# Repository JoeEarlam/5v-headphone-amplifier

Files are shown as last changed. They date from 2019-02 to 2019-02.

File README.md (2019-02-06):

# 5v-headphone-amplifier

A small, op-amp based headphone amplifier with a BOM cost of under £10 - think CMOY on steroids. Designed to run from 5V power, specifically cheap single-cell USB powerbanks, where it can be stuck to the side with velcro or double sided tape.

Uses an RC4580D, but any standard footprint SOIC-8 op-amp can be substituted.

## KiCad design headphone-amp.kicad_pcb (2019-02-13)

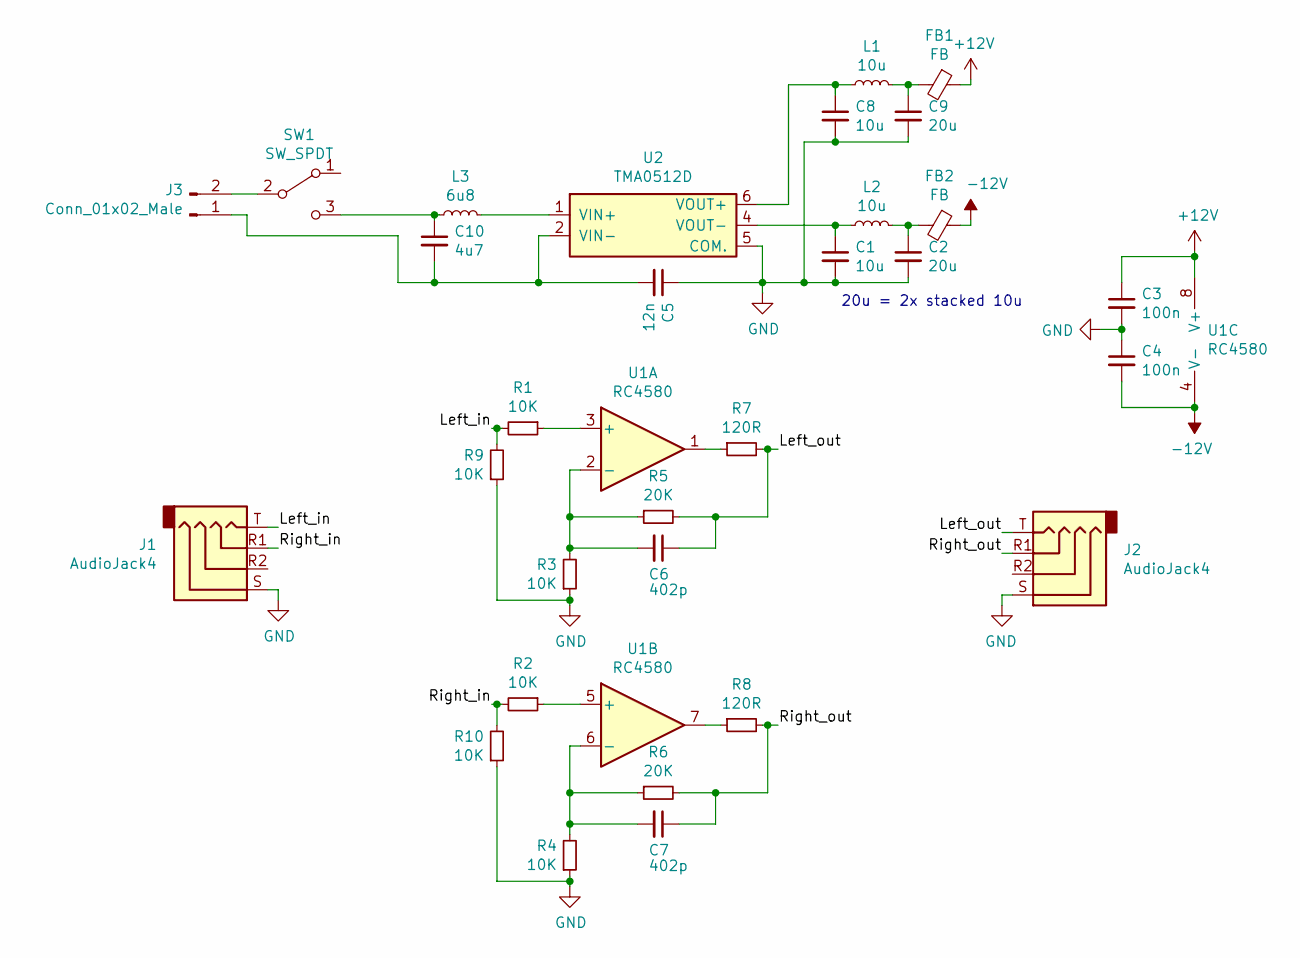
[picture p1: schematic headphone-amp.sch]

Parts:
C1, C8: 10u; C_0805_2012Metric
C2, C9: 20u; C_0805_2012Metric
C3, C4: 100n; C_0805_2012Metric
C5: 12n; C_0805_2012Metric
C6, C7: 402p; C_0805_2012Metric
C10: 4u7; C_0805_2012Metric
FB1, FB2: FB; L_0805_2012Metric
J1, J2: AudioJack4; Jack_3.5mm_PJ320D_Horizontal
J3: Conn_01x02_Male; JST_PH_S2B-PH-SM4-TB_1x02-1MP_P2.00mm_Horizontal
L1, L2: 10u; L_0805_2012Metric
L3: 6u8; L_0805_2012Metric
R1, R2, R3, R4, R9, R10: 10K; R_0805_2012Metric
R5, R6: 20K; R_0805_2012Metric
R7, R8: 120R; R_0805_2012Metric
SW1: SW_SPDT; SW_SPDT_CK-JS102011SAQN
U1: RC4580; SOIC-8_3.9x4.9mm_P1.27mm
U2: TMA0512D; TMAxxxxD_horizontal

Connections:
+12V: C3.1, FB1.1, U1.8 (V+)
-12V: C4.2, FB2.1, U1.4 (V-)
/Left_in: J1.T, R1.2, R9.2
/Left_out: C6.1, J2.T, R5.2, R7.2
/Right_in: J1.R1, R2.2, R10.2
/Right_out: C7.1, J2.R1, R6.2, R8.2
GND: C1.2, C2.2, C3.2, C4.1, C5.1, C8.2, C9.2, J1.S, J2.S, R3.1, R4.1, R9.1, R10.1, U2.5 (COM.)
unnamed: C1.1, L2.1, U2.4 (VOUT-)
unnamed: C2.1, FB2.2, L2.2
unnamed: C6.2, R3.2, R5.1, U1.2 (-)
unnamed: C7.2, R4.2, R6.1, U1.6 (-)
unnamed: C8.1, L1.1, U2.6 (VOUT+)
unnamed: C9.1, FB1.2, L1.2
unnamed: C10.1, L3.1, SW1.3 (C)
unnamed: C5.2, C10.2, J3.1, U2.2 (VIN-)
unnamed: J3.2, SW1.2 (B)
unnamed: L3.2, U2.1 (VIN+)
unnamed: R1.1, U1.3 (+)
unnamed: R2.1, U1.5 (+)
unnamed: R7.1, U1.1
unnamed: R8.1, U1.7

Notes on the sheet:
20u = 2x stacked 10u

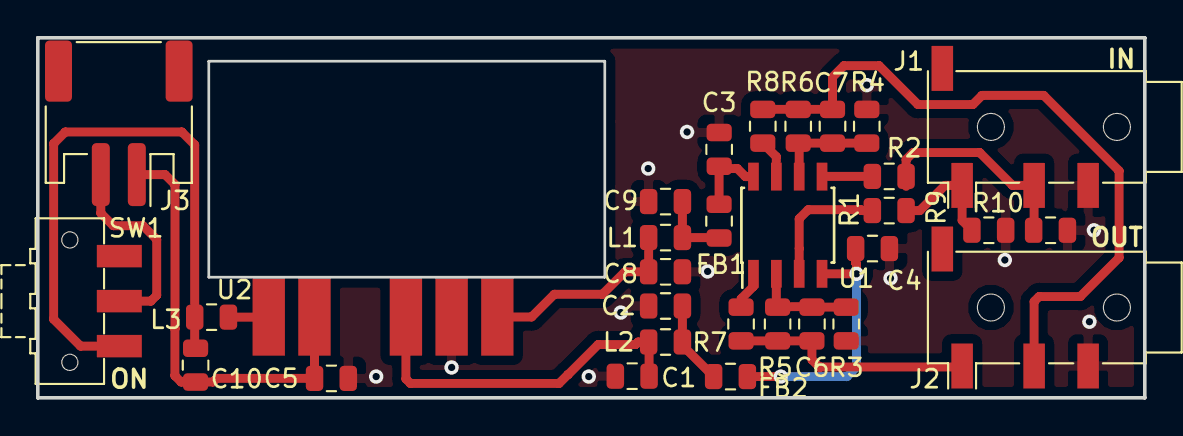
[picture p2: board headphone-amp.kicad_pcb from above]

Board: 2 copper layers, 61.5 x 20.0 mm, 31 parts (0 on the bottom side), 21 nets.

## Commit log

2019-02-06 changed feedback networks slightly
    [headphone-amp.kicad_pcb, headphone-amp.sch]
2019-02-07 tag for prototype production
    [headphone-amp.kicad_pcb, headphone-amp.sch]
2019-02-07 changed filtering network
    [headphone-amp.kicad_pcb, headphone-amp.sch]
2019-02-10 as sent to production
    [headphone-amp.kicad_pcb]
2019-02-12 minor changes to filtering networks
    [headphone-amp.kicad_pcb, headphone-amp.sch]
2019-02-12 added input filtering to DC-DC converter
    [headphone-amp.kicad_pcb, headphone-amp.sch]
2019-02-13 Added input resistors
    [headphone-amp.kicad_pcb, headphone-amp.sch]
